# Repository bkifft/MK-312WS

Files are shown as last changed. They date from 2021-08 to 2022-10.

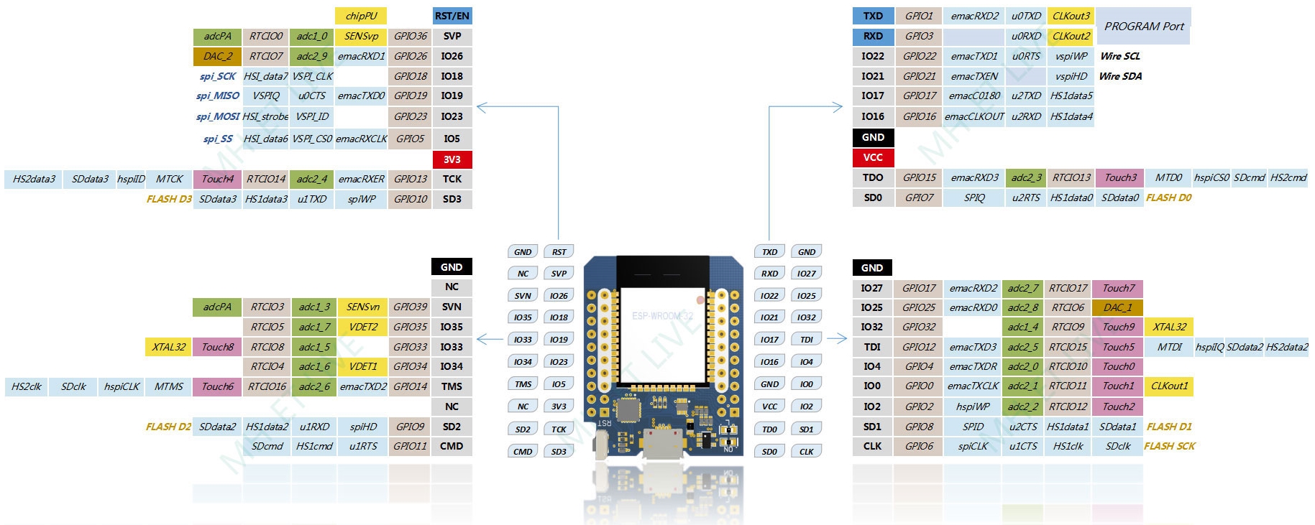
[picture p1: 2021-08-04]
datasheets/esp32minikit.jpg

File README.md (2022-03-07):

# MK-312WS
ESP32 based webserver as replacement for the HC05/06 inside a MK-312BT.

Can join a WPA2 encrypted WLAN, or be it's own AP.
For now does the knobs, program, ramp and battery level. 
mk-312ws-gui

Planned features:
- Ramp parameters.
- Other advanced parameters, like freq and width.
- Powerlevel.
- User program upload.
- MA ramp.
- Interaction recording / playback.

Requirements:
- ESP32 devboard. I recommend the "ESP32 mini", 2x2x10 pins. Like https://www.az-delivery.de/en/products/esp32-d1-mini, does get sold under different brands.
- ~~Levelshifter, 5V to 3.3V. Already part of the carrier board.~~ Turns out levelshifting isn't needed, as there's already a voltage divider on the boxes TX line.
- Arduino IDE with the ESP32 board package and the filesystem uploader (https://randomnerdtutorials.com/install-esp32-filesystem-uploader-arduino-ide/).

Howto:
- Flash the sketch.
- Flash the filesystem.
- Replace the BT module in the mk312. ~~Remember to levelshift RX if you aren't using the carrier board.~~
- Connect to the new AP. SSID is the modules MAC address, pw is 12345678.
- Open http://192.168.4.1/config. Change the SSID if you want to continue AP mode, SSID and password to connect to a preexisting network.
WARNING: For now AP mode will always use the default password of 12345678, as there is no easy other way to change a forgotten password.
- Open http://mk-312ws.local (or the respective new hostname if you changed it) and start zapping.

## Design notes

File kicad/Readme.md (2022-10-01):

The Kicad files may not repressent a stable configuration.
Better to use the gerber zips if you just want to order.

v4 seems to be buggy, use v3 for now

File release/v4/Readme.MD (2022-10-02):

Warning:
If you are running an older version (no version information at bottom of pages), you will need to do a USB based flash first, as I had to change the partitioning scheme.
Details on how to do this will follow.

Short version:

Windows:
- Get Flash Download Tools from https://www.espressif.com/en/support/download/other-tools
- Connect board using microUSB cable
- In tool select esp32, develop, ok.
- In first line tick checkbox, open USB-flash.bin, enter 0x0 (that's zeroxzero) into last field.
- Select virtual com port in bottom right
- Click Start

esptool.py:
- Install esptool.py. Available via apt, pip, homebrew and otheer package managers.
- Connect board using microUSB cable
- run 
esptool.py --chip esp32 --port /dev/ttyUSB0 --baud 460800  --before default_reset --after hard_reset write_flash -z --flash_mode dio --flash_freq 80m --flash_size detect 0x0 USB-flash.bin

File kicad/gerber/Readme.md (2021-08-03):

v1 and v2 have a design error. IO2 must be pulled low during flash, but gets pulled high by the pullup.
Easy fix: Cut the pin connectiong to IO2, and bridge IO2 and IO0 using a solder bridge.

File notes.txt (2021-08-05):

- using d1 mini esp32. might need to change gpio on different platforms.
- many esp32 boards are not 5V tolerant
- bt overrules webserver?

"Warning: Could not auto-detect Flash size (FlashID=0xffffff, SizeID=0xff), defaulting to 4MB"
-> module faulty, flashchip. check gpio  pins 6,7,8,9,10 & 11.

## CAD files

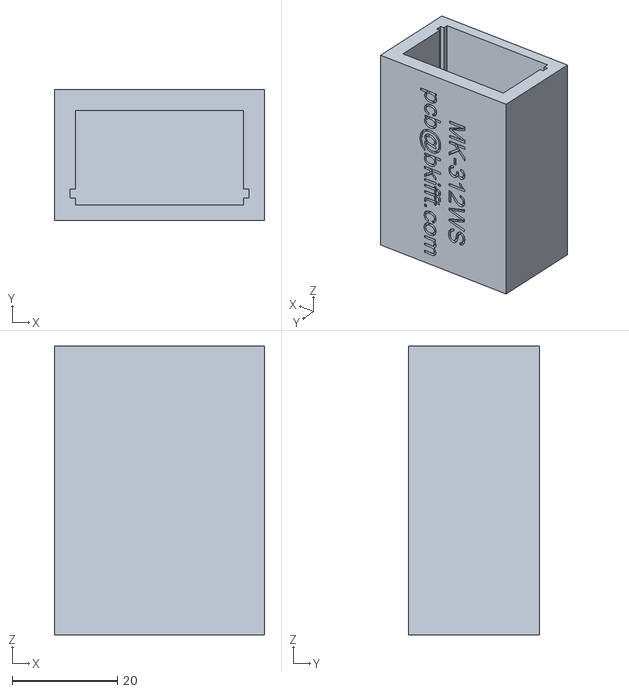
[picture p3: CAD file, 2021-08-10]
stl/mk-312ws transporter v4.stl
40.0 x 25.0 x 55.0

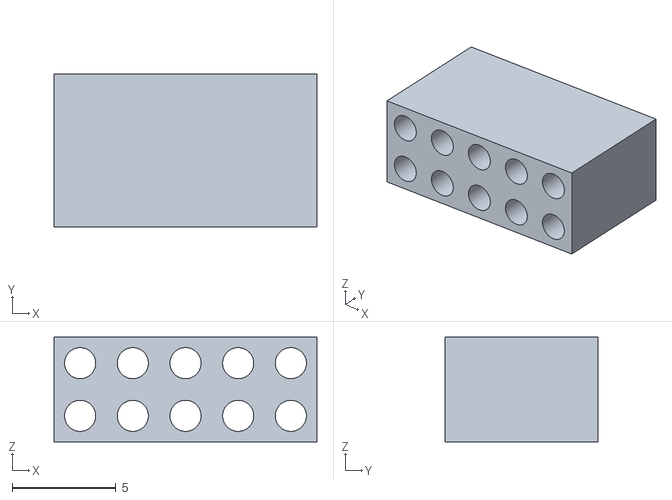
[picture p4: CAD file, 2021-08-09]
stl/pincover_2x5.stl
12.7 x 7.40 x 5.06

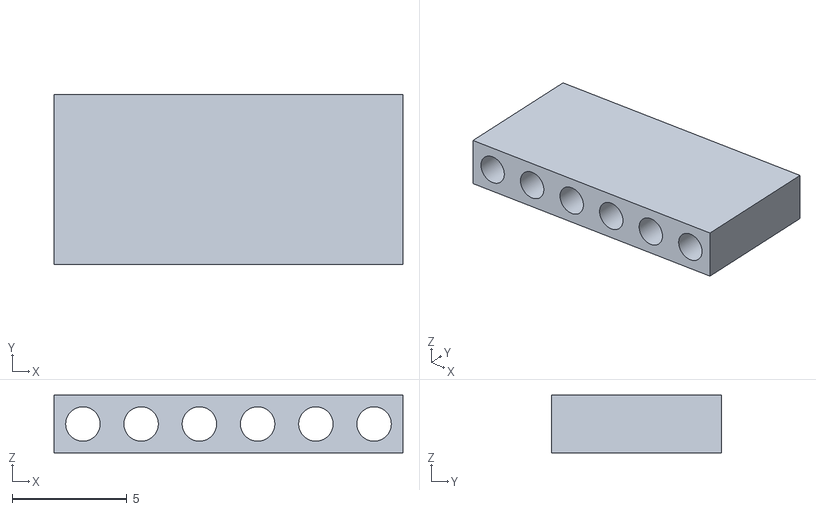
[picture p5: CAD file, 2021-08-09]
stl/pincover_1x6.stl
15.2 x 7.40 x 2.52

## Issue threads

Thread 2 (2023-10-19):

Webcontrol

Matthew818ply, 2023-10-19:
Web Interface doesn't seem to control the box. Have flashed the Arduino sketch and filesystem.

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

Matthew818ply, 2023-10-19:
Here's how the web interface looks.
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

Kawaiito, 2023-11-02:
have the same problem and the sketch dont work with the newest libarys

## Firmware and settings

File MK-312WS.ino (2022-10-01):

#include <Arduino.h>
#include "BluetoothSerial.h"
#include <WiFi.h>
#include <AsyncTCP.h>
#include <ESPAsyncWebServer.h>
#include <SPIFFS.h>
#include <Arduino_JSON.h>
#include <ESPmDNS.h>
#include <Preferences.h>
#include <AsyncElegantOTA.h>

#include "mk312.h"


//////////change here

const String default_hostname = "MK-312WS";
const String default_ssid = WiFi.macAddress();
const String default_password = "12345678"; //needs to be at least 8 chars long for AP mode
const bool default_bt_mode = false;
const int retry_limit = 10;
const String fw_version = "0.4";
/////////stop changing

const char* hex_table = "0123456789abcdef";

AsyncWebServer server(80);
AsyncWebSocket ws("/ws");
AsyncWebSocket ws_bytes("/ws_bytes");

BluetoothSerial SerialBT;
bool bt_mode;

Preferences preferences;
String ssid;
String password;
String hostname;
String preferences_namespace;

JSONVar values;
String json_string;

void init_bt()
{
 Serial2.begin(19200);  
 SerialBT.begin("MK312");
}

void init_fs()
{
  if (!SPIFFS.begin())
  {
    Serial.println("error: fs");
  }
  else
  {
    Serial.println("fs running");
  }
}

void init_preferences()
{
  preferences_namespace = WiFi.macAddress();
  preferences_namespace.replace(":", "");
  Serial.println("loading preferences, namespace " + preferences_namespace);
  if (!preferences.begin(preferences_namespace.c_str()))
  {
    Serial.println("error: preferences!");
    ssid = default_ssid;
    password = default_password;
    hostname = default_hostname;
    bt_mode = default_bt_mode;
  }
  else
  {
    ssid = preferences.getString("ssid", default_ssid);
    password = preferences.getString("password", default_password);
    hostname = preferences.getString("hostname", default_hostname);
    bt_mode = preferences.getBool("bt_mode", default_bt_mode);

    preferences.end();
    Serial.println("preferences loaded");
  }

  Serial.print("ssid: ");Serial.println( ssid);
  Serial.print("hostname: ");Serial.println( hostname);
    Serial.print("bt_mode: ");Serial.println( bt_mode);

}


String template_processor(const String& var)
{
  if (var == "HOSTNAME")
  {
    return hostname;
  }
  if (var == "FWVERSION")
  {
    return fw_version;
  }
  
  return String();
}

void init_wifi()
{
  int count = 0;
  WiFi.mode(WIFI_STA);
  WiFi.begin(ssid.c_str(), password.c_str());
//  Serial.println("Connecting to WiFi ");
  while (++count < retry_limit && WiFi.status() != WL_CONNECTED)
  {
    Serial.print('.');
    delay(1000);
  }
  Serial.println("");
  if (WiFi.status() == WL_CONNECTED)
  {
    Serial.println("Connected to " + ssid);
    Serial.println("IP address: " + WiFi.localIP().toString());
  }
  else
  {
    WiFi.disconnect();
    ssid = ssid.substring(0, 30) + "MK"; //ssid is specced at max 32 characters. neded in case wrong pw to join existing wifi
    WiFi.softAP(ssid.c_str(), default_password.c_str());
    Serial.println("AP-Mode");
    Serial.println("IP address: " + WiFi.softAPIP().toString());
  }
  /*use mdns for host name resolution*/
  if (!MDNS.begin(hostname.c_str()))
  {
    Serial.println("error: mdns");
  }
  else
  {
    Serial.println("mdns running: " + hostname + ".local");
  }
}

void update_knobs()
{
  values["slider_a"] = mk312_get_a();
  values["slider_b"] = mk312_get_b();
  values["slider_m"] = mk312_get_ma();

}
/*
void handleWebSocketMessage_ws_bytes(void *arg, uint8_t *data, size_t len)
{
  AwsFrameInfo *info = (AwsFrameInfo*)arg;

  if (info->final && info->index == 0 && info->len == len && info->opcode == WS_TEXT)
  {

  }

}
*/
void handleWebSocketMessage_ws(void *arg, uint8_t *data, size_t len)
{
  AwsFrameInfo *info = (AwsFrameInfo*)arg;
  int slider;
  char* message;
  byte newmode;

  if (info->final && info->index == 0 && info->len == len && info->opcode == WS_TEXT)
  {
    data[len] = 0;
    message = (char*)data;
    //serial.println(message);
    Serial.println("ws-command: " + String(message));
    char c[16];

    switch (message[0])
    {
      case 'r': //ramp
        switch (message[5])
        {
          case 'l':
            //     values["ramp_level"] = mk312_get_ramp_level();

            break;

          case 't':
            //   values["ramp_time"] = mk312_get_ramp_time();

            break;
          case 's':
            mk312_ramp_start();
            break;
        }
        break;

      case 'e': //emergency stop
         mk312_all_off();
         values["slider_a"] = mk312_get_a();
         values["slider_b"] = mk312_get_b();
         break;

      case 's': //slider
        slider = atoi(message + 9);
        switch (message[7])
        {
          case 'a':
            mk312_set_a(slider);
            values["slider_a"] = mk312_get_a();
            break;

          case 'b':
            mk312_set_b(slider);
            values["slider_b"] = mk312_get_b();
            break;

          case 'm':
            mk312_set_ma(slider);
            values["slider_m"] = mk312_get_ma();
            break;
        }
        break;

      case 'm'://mode
        newmode = strtol(message + 5, NULL, 16);
        mk312_set_mode(newmode);

        //this puts the mode char as human readable 0x notation into c[]
        c[0] = mk312_get_mode();
        c[1] = 'x';
        c[2] = hex_table[c[0] >> 4];
        c[3] = hex_table[c[0] & 0xf];
        c[0] = '0';
        c[4] = '\0';
        values["mode"] = c;
        break;

      case 'a'://adc
        if (message[5] == 'n')//on
        {
          mk312_enable_adc();
        }
        else
        {
          mk312_disable_adc();
        }
        values["adc"] = mk312_get_adc_disabled() ? "off" : "on";
        update_knobs();
        break;

      case 'b'://bytes
        
        break;

      case 'i'://inc
        switch (message[4])
        {
          case 'a':
            mk312_inc_a();
            values["slider_a"] = mk312_get_a();
            break;

          case 'b':
            mk312_inc_b();
            values["slider_b"] = mk312_get_b();
            break;

          case 'm':
            mk312_inc_ma();
            values["slider_m"] = mk312_get_ma();
            break;
        }
        break;

      case 'd'://dec
        switch (message[4])
        {
          case 'a':
            mk312_dec_a();
            values["slider_a"] = mk312_get_a();
            break;

          case 'b':
            mk312_dec_b();
            values["slider_b"] = mk312_get_b();
            break;

          case 'm':
            mk312_dec_ma();
            values["slider_m"] = mk312_get_ma();
            break;
        }
        break;



    }

    values["battery"] = mk312_get_battery_level();
    json_string = JSON.stringify(values);
    ws.textAll(json_string);
  }
}

void onEvent_ws(AsyncWebSocket *server, AsyncWebSocketClient *client, AwsEventType type, void *arg, uint8_t *data, size_t len) {
  switch (type)
  {
    case WS_EVT_CONNECT:
      //serial.printf("WebSocket client #%u connected from %s\n", client->id(), client->remoteIP().toString().c_str());
      break;
    case WS_EVT_DISCONNECT:
      //serial.printf("WebSocket client #%u disconnected\n", client->id());
      break;
    case WS_EVT_DATA:
      handleWebSocketMessage_ws(arg, data, len);
      break;
    case WS_EVT_PONG:
    case WS_EVT_ERROR:
      break;
  }
}

/*void onEvent_ws_bytes(AsyncWebSocket *server, AsyncWebSocketClient *client, AwsEventType type, void *arg, uint8_t *data, size_t len) {
  switch (type)
  {
    case WS_EVT_CONNECT:
      //serial.printf("WebSocket client #%u connected from %s\n", client->id(), client->remoteIP().toString().c_str());
      break;
    case WS_EVT_DISCONNECT:
      //serial.printf("WebSocket client #%u disconnected\n", client->id());
      break;
    case WS_EVT_DATA:
      handleWebSocketMessage_ws_bytes(arg, data, len);
      break;
    case WS_EVT_PONG:
    case WS_EVT_ERROR:
      break;
  }
}
*/

void init_ws()
{
  ws.onEvent(onEvent_ws);
  server.addHandler(&ws);
 // ws_bytes.onEvent(onEvent_ws_bytes);
 // server.addHandler(&ws_bytes);
}


void setup() {
  values["slider_a"] = 0;
  values["slider_b"] = 0;
  values["slider_m"] = 0;
  values["mode"] = "0x76";
  values["adc"] = "on";
  values["battery"] = 0;
  //values["ramp_level"] = 5;
  //values["ramp_time"] = 5;
  json_string = JSON.stringify(values);

  Serial.begin(115200);
  pinMode(0, OUTPUT);
  pinMode(2, OUTPUT);
  init_fs();
  init_preferences();
  init_wifi();

if (bt_mode)
{
  init_bt();
   server.on("/", HTTP_GET, [](AsyncWebServerRequest * request)
  {
    request->send(SPIFFS, "/btmode.html", "text/html", false, template_processor);
  });
}
else
{
  delay(1000);
  init_mk312_easy();
  init_ws();


  server.on("/", HTTP_GET, [](AsyncWebServerRequest * request)
  {
    request->send(SPIFFS, "/index.html", "text/html", false, template_processor);
  });
}
  server.on("/config", HTTP_GET, [](AsyncWebServerRequest * request)
  {
    request->send(SPIFFS, "/config.html", "text/html", false, template_processor);
  });

  server.on("/config_post", HTTP_POST, [](AsyncWebServerRequest * request)
  {
    if (request->hasParam("ssid", true)) ssid = request->getParam("ssid", true)->value();
    if (request->hasParam("password", true)) password = request->getParam("password", true)->value();
    if (request->hasParam("hostname", true)) hostname = request->getParam("hostname", true)->value();
    if (request->hasParam("bt_mode", true)) //only triggers if checked
    {
      bt_mode = true;
    }
    else
    {
      bt_mode = false;
    }
/*int args = request->args();
for(int i=0;i<args;i++){
  Serial.printf("ARG[%s]: %s\n", request->argName(i).c_str(), request->arg(i).c_str());
  
}*/
    Serial.println("new ssid: " + ssid);
    Serial.println("new hostname: " + hostname);

    preferences.begin(preferences_namespace.c_str());
    if (ssid.length() > 0 ) preferences.putString("ssid", ssid);
    if (password.length() > 0 ) preferences.putString("password", password);
    if (hostname.length() > 0 ) preferences.putString("hostname", hostname);
    preferences.putBool("bt_mode", bt_mode);

    preferences.end();
    request->send(200, "text/plain", "CONFIG UPDATED");
  });

  server.on("/reset", HTTP_GET, [](AsyncWebServerRequest * request)
  {
    preferences.begin(preferences_namespace.c_str(), false);
    preferences.clear();
    preferences.end();
    request->send(200, "text/plain", "RESET DONE");
  });

  server.serveStatic("/", SPIFFS, "/");
  AsyncElegantOTA.begin(&server);//, ssid.c_str(), password.c_str());//FIXME: reenable update login
  server.begin();
  digitalWrite(0, HIGH);
  digitalWrite(2, HIGH);
}


void loop() {
  char c;
  if (bt_mode)
  //no locking required, bt mode is 1:1 for now
  {
    if (Serial2.available()) {
      c = Serial2.read();
      SerialBT.write(c);
     // Serial.print("in  ");
     // Serial.println(c, HEX);
      
    }
    if (SerialBT.available()) {
      c = SerialBT.read();
      Serial2.write(c);
    //  Serial.print("out ");
     // Serial.println(c, HEX);
      
    }
  }
  else
  {
      ws.cleanupClients();
  }
}

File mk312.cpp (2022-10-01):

#include <Arduino.h>
#include <HardwareSerial.h>
#include "mk312.h"
#include <esp_task_wdt.h>



SemaphoreHandle_t  semaphore_serial2;
byte key = 0x55;
const int retry_limit = 4;
String leftover;
const int timeout = 250;

/*
   0xGd 0xHH 0xII [0xJJ 0xKK...] 0xCC

  0xGd - High nibble is amount of data to write to address plus 0x3, low nibble is always 0x0d
  0xHH - High byte of address
  0xII - Low byte of address
  [0xJJ 0xKK]... - Value(s) to set address to
  0xCC - Checksum
*/

bool mk312_write_single (uint16_t address, byte* payload, size_t length)
{
  if (length > 8)
  {
    Serial.println("error: mk312_write longer than eight bytes");
    return false;
  }
  byte c[16];
  byte sum;
  int i;
  c[0] = 0x3d + (length << 4);
  c[1] = (address >> 8) & 0xff;
  c[2] = address & 0xff;
  sum = (c[0] + c[1] + c[2]) & 0xff;
  for (i = 0; i < length; i++)
  {
    c[i + 3] = payload[i];
    sum = (sum + payload[i]) & 0xff;
  }
  c[length + 3] = sum;
  for (i = 0; i < length + 4; i++)
  {
    c[i] = c[i] ^ key;
  }
  leftover = "";
  if (xSemaphoreTake(semaphore_serial2,  portTICK_PERIOD_MS * 2 * timeout) == pdTRUE)
  {
    while (Serial2.available())
    {
      leftover = leftover + String(Serial2.read(), HEX);
    }
    if (leftover.length() > 0)
    {
      Serial.println("leftovers in write: " + leftover);
    }
    Serial2.write(c, length + 4);
    c[0] = '\0';
    Serial2.readBytes(c, 1);
    xSemaphoreGive(semaphore_serial2);
  }
  else
  {
    Serial.println("error: write didn't get semaphore");
    return false;
  }

  if (c[0] != 0x06)
  {
    Serial.println("error: received wrong write reply, got " + String(c[0], HEX));
    return false;
  }
  return true;
}

void mk312_write (uint16_t address, byte* payload, size_t length)
{
  for (int i = 0; i < retry_limit; i++)
  {
    esp_task_wdt_reset();
    if (mk312_write_single(address, payload, length))
    {
      return;
    }
    Serial.println("error: failed mk312_write " + String(address, HEX) +" try " + i);
    
  }
}


/*
  0x3c 0xGG 0xHH 0xCC
  0xHH - High byte of address
  0xII - Low byte of address
  0xCC - Checksum
  The box will then respond with two bytes (plus checksum, as above)

  0x22 0xVV 0xCC
  0xVV - Content of requested address
  0xCC - Checksum

*/
bool mk312_read_single (uint16_t address, byte* retval)
{
  byte c[4];
  byte sum;
  int i;

  c[0] = 0x3c;
  c[1] = (address >> 8) & 0xff;
  c[2] = address & 0xff;
  c[3] = c[0] + c[1] + c[2];

  for (i = 0; i < 4; i++)
  {
    c[i] = c[i] ^ key;
  }
  leftover = "";
  if (xSemaphoreTake(semaphore_serial2, portTICK_PERIOD_MS * 2 * timeout) == pdTRUE)
  {
    while (Serial2.available())
    {
      leftover = leftover + String(Serial2.read(), HEX);
    }
    if (leftover.length() > 0)
    {
      Serial.println("leftovers in read: " + leftover);
    }
    Serial2.write(c, 4);
    memset(c, '\0', 3);
    Serial2.readBytes(c, 3);
    xSemaphoreGive(semaphore_serial2);
  }
  sum = c[0] + c[1];
  if (sum != c[2])
  {
    Serial.println("error: wrong read checksum expected and got " + String(sum, HEX) + String(c[2], HEX));
    return false;
  }

  if (c[0] != 0x22)
  {
    Serial.println("error: wrong read reply got " + String(c[0], HEX));
    return false;
  }

  *retval = c[1];
  return true;
}


byte mk312_read (uint16_t address)
{
  byte retval = 0;
  for (int i = 0; i < retry_limit; i++)
  {
    esp_task_wdt_reset();
    if (mk312_read_single(address, &retval))
    {
      return retval;
    }
    Serial.println("error: failed mk312_read " + String(address, HEX) +" try " + i);
  }
  return retval;
}

/* deprecated for easyinit
//write 0x00 untill reading 0x07. must happen no later than 11 bytes
void mk312_sync() {
  int i;
  byte c;
  size_t count;

  for (i = 0; i < 11; i++)
  {
    c = 0x00 ^ key;
    if (xSemaphoreTake(semaphore_serial2, portTICK_PERIOD_MS * 2 * timeout) == pdTRUE)
    {
      while (Serial2.available())
      {
        leftover = leftover + String(Serial2.read());
      }
      if (leftover.length() > 0)
      {
        Serial.println("leftovers in sync: " + leftover);
      }
      Serial2.write(&c, 1);
      count = Serial2.readBytes(&c, 1);
      xSemaphoreGive(semaphore_serial2);
    }
    if (count > 0)
    {
      break;
    }

  }

  if (i >= retry_limit)
  {
    Serial.println("error: mk312 sync no reply");
  }
  if (c != 0x07)
  {
    Serial.println("error: mk312 sync wrong reply");
  }
}
*/

void mk312_enable_adc()
{
  byte c = mk312_read(ADDRESS_R15);
  c = c & ~(1 << REGISTER_15_ADCDISABLE);
  mk312_write(ADDRESS_R15, &c, 1);
}

void mk312_disable_adc()
{
  byte c = mk312_read(ADDRESS_R15);
  c = c | (1 << REGISTER_15_ADCDISABLE);
  mk312_write(ADDRESS_R15, &c, 1);
}

bool mk312_get_adc_disabled()
{
  byte c = mk312_read(ADDRESS_R15);

  if (c & (1 << REGISTER_15_ADCDISABLE))
  {
    return true;
  }
  return false;
}

void mk312_all_off()
{
  mk312_set_a(0);
  mk312_set_b(0);
}


void mk312_set_a(int percent)
{
  if (!mk312_get_adc_disabled())
  {
    return;
  }
  byte value = map(percent, 0, 99, 0, 255);
  mk312_write(ADDRESS_LEVELA, &value, 1);
}

void mk312_set_b(int percent)
{
  if (!mk312_get_adc_disabled())
  {
    return;
  }
  byte value = map(percent, 0, 99, 0, 255);
  mk312_write(ADDRESS_LEVELB, &value, 1);
}

void mk312_set_ma(int percent)
{
  if (!mk312_get_adc_disabled())
  {
    return;
  }
  byte ma_max;
  byte ma_min;
  byte value;

  ma_max = mk312_read(ADDRESS_MA_MAX_VALUE);
  ma_min = mk312_read(ADDRESS_MA_MIN_VALUE);
  value = map(percent, 0, 100, ma_max, ma_min);
  Serial.printf("set_ma: max %02x min %02x val %02x\r\n", ma_max, ma_min, value);
  mk312_write(ADDRESS_LEVELMA, &value, 1);

}

void mk312_set_mode(byte newmode)
{
  if (newmode == mk312_read(ADDRESS_CURRENT_MODE))
  {
    return;
  }
  byte commands[2] =
  {
    COMMAND_EXIT_MENU,
    COMMAND_NEW_MODE
  };
  mk312_write(ADDRESS_CURRENT_MODE, &newmode, 1);
  mk312_write(ADDRESS_COMMAND_1, commands, 2);
}

byte mk312_get_ramp_level()
{
  return mk312_read(ADDRESS_RAMP_LEVEL);
}

byte mk312_get_ramp_time()
{
  return mk312_read(ADDRESS_RAMP_TIME);
}

void mk312_set_ramp_level()
{
  
}

void mk312_set_ramp_time()
{
  
}

void mk312_ramp_start()
{
  byte c[2] = { COMMAND_START_RAMP, 0x02};
  mk312_write(ADDRESS_COMMAND_1, c, 2);
}

int mk312_get_battery_level()
{
  return map(mk312_read(ADDRESS_BATTERY_LEVEL), 0, 255, 0, 99);
}

int mk312_get_a()
{
  int value;
  value = mk312_read(ADDRESS_LEVELA);
  value = map(value, 0, 255, 0, 99);
  return value;
}

int mk312_get_b()
{
  int value;
  value = mk312_read(ADDRESS_LEVELB);
  value = map(value, 0, 255, 0, 99);
  return value;
}

int mk312_get_ma()
{
  byte ma_max;
  byte ma_min;
  byte value;

  ma_max = mk312_read(ADDRESS_MA_MAX_VALUE);
  ma_min = mk312_read(ADDRESS_MA_MIN_VALUE);
  value = mk312_read(ADDRESS_LEVELMA);
  value = map(value,  ma_max, ma_min, 0, 99);
  return value;
}

byte mk312_get_mode()
{
  return mk312_read(ADDRESS_CURRENT_MODE);
}
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

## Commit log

2021-07-14 erste experimente. webupdate und config mit ap fallback gehn.
    jetzt bissi löten, dann direkt ab ins mk und mit den chars ficken
2021-07-15 mehmeh arduino nameregeln
2021-07-20 neuschreib mit funzenden slidern und vernünftigem ota
2021-07-21 uart teil eins. ein graus
2021-07-21 read und write schaun gut aus. jetzt die spezifischen dinge
2021-07-21 modi und adw vorderseite
2021-07-21 ws parse switch
2021-07-22 neugetan der modi
2021-07-23 v1 des gedruckten schaltbretts
    [mk312ws.kicad_pcb, mk312ws.sch]
2021-07-24 adapter v2. größere pads und jumper für serial 1 loopback
    [mk312ws.kicad_pcb, mk312ws.sch]
2021-07-27 aufgeräumt, lasst die ersten gäste rein
2021-07-29 board version 2, hauptsächlich leichter zu löten
2021-07-30 brocken. die du points müssen aus dem schotten
2021-07-31 anfang des ausgliederns von entkäfern
2021-08-04 kann ja keiner ahnen, dass io2 beim blitz niedrig sein muss
    [mk312ws.kicad_pcb, mk312ws.sch]
2021-08-05 entkäferung zeigt, dass eines der bretter verhext ist
2021-08-06 v3 mehr dinge. mehr fluten, mehr ausrichten
    [mk312ws.kicad_pcb, mk312ws.sch]
2021-08-09 blindstecker. kann man immer brauchen
    [pincover_1x6.stl, pincover_2x5.stl]
2021-08-10 Logistikschächtelchen
    [mk-312ws transporter v4.stl]
2021-10-02 wenn der entkäferer verkäfert ist gehts auch mal ohne
2022-02-22 andere ssid wenn es probleme gibt
    [MK-312WS.ino]
2022-05-07 v4 carrierboard. no more active components, just pins.
    [mk312ws.kicad_pcb, mk312ws.kicad_sch]
2022-09-15 Delete mk-312ws-gerber_v4.zip
    buggy v4 board
